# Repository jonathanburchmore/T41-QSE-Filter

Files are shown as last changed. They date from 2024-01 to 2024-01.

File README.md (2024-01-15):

# 5-Band Switching QSE Filter for T41 v11 and Older
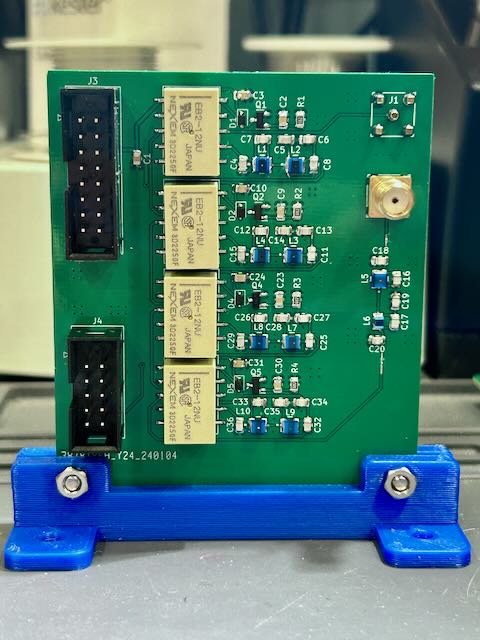
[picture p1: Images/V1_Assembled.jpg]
v1 Assembled


## Overview
This project is an automatically switched, 5-band filter board for V11 and older of the T41-EP.  Installed between the QSE and PA boards, these filters reduce harmonics that cause distortion in the PA output that cannot be removed by the output filter board.

This board is compatible with the V11 and older band switch signaling and uses a similar design to the V11 and older filter board.  The 10m filter is always active, and the 80, 40, 20 and 15 meter filters are switched in and out using relays.  With the current filter design, the 10m filter does introduce some insertion loss (see Insertion Loss below).

## Filter Characteristics
The filters used are from the ARRL Handbook, 99th edition, chapter 10.10.4 Optimized Harmonic Transmitting Filters.  They are low-pass filters (not band-pass), and are constructed using SMD components.  Most inductors are Coilcraft 1008CS series (1008 footprint), except for one Murata 0805 inductor in the 10m filter, as there was no 1008 footprint equivalent.

The following filter sweeps include the 10m filter in place so they reflect the loss characteristics described below for the lower bands.

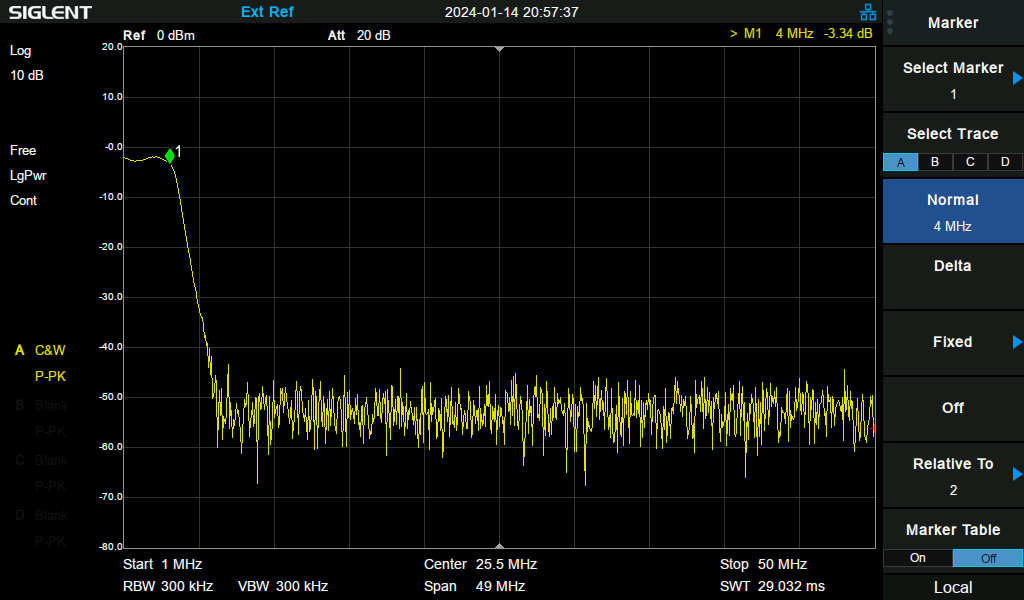
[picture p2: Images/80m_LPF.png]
80m LPF


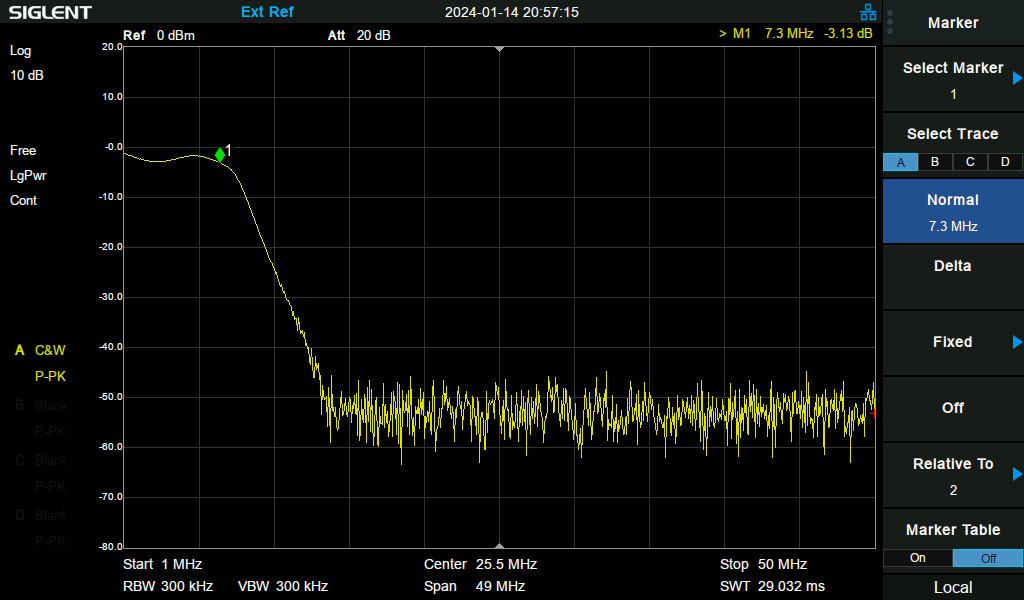
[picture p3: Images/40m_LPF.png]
40m LPF


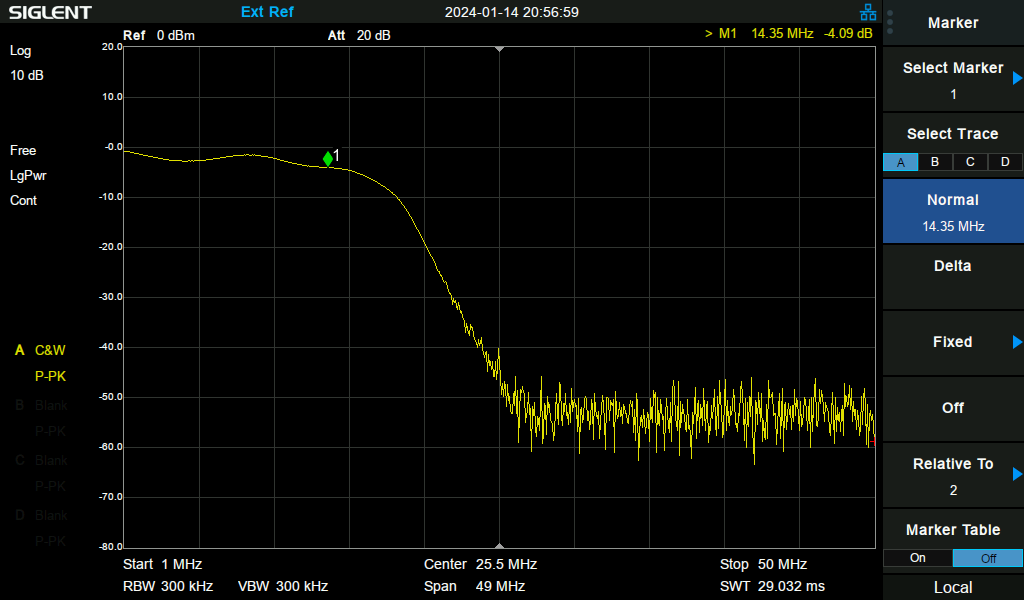
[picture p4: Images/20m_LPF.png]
20m LPF


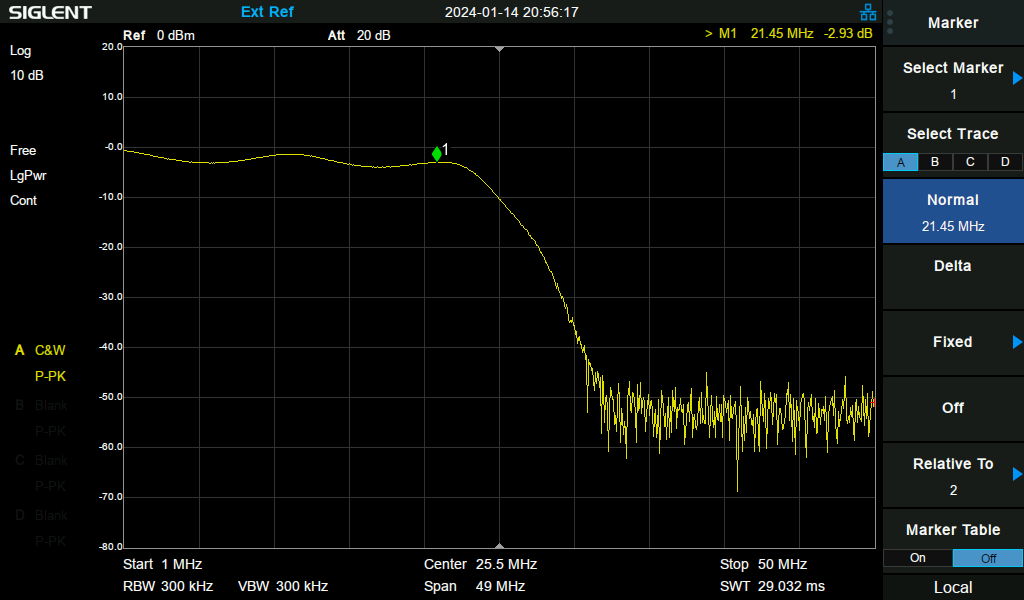
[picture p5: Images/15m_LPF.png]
15m LPF


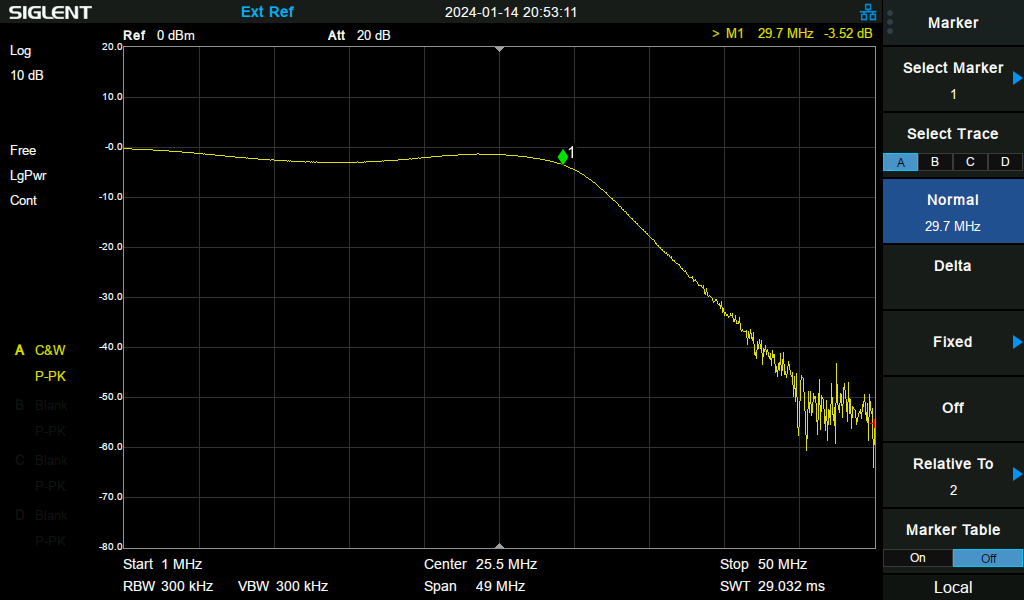
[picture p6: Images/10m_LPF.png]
10m LPF


## Insertion Loss
The PCB design is 2-layer and the RF traces are not impedance matched.  Despite this, the board itself shows negligible insertion loss and a relatively flat SWR through 35MHz.

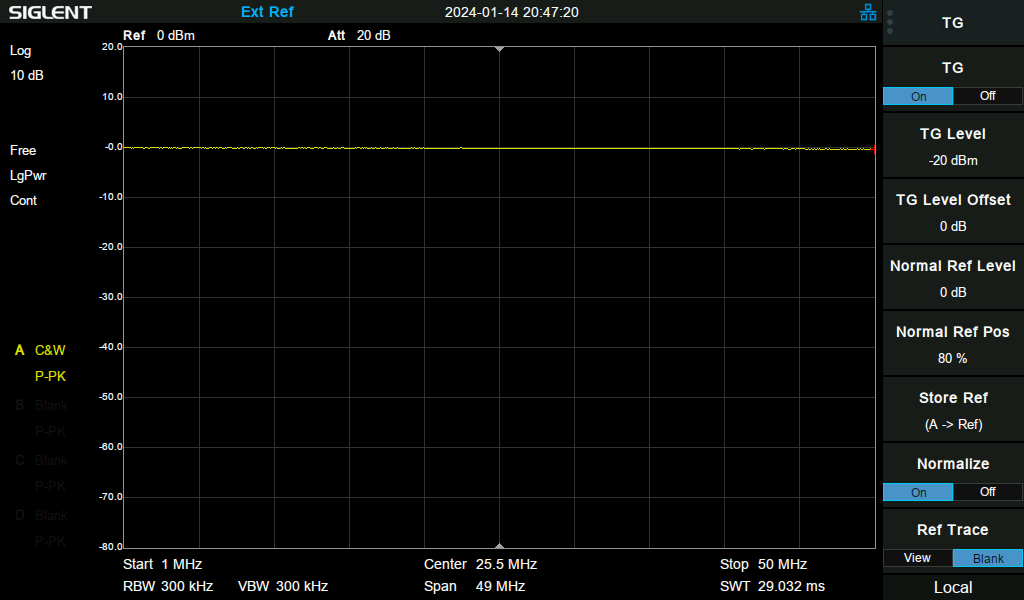
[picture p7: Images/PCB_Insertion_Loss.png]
Insertion Loss thru 50MHz


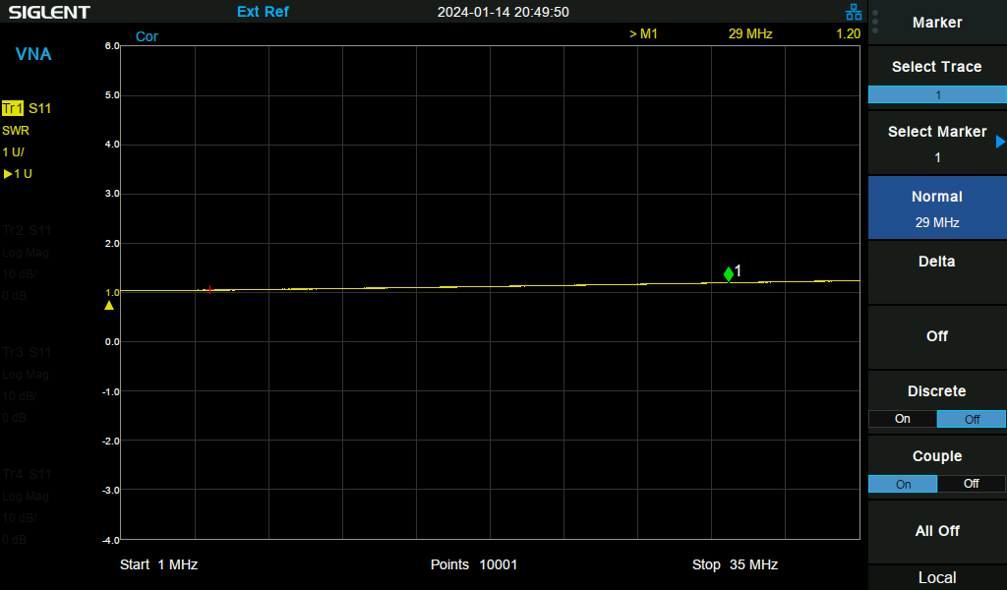
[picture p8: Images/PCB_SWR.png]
SWR through 35MHz


Nevertheless, as can be seen from the filter sweeps above, most of the filters demonstrate approximately 3db of loss.  This is largely due to the presence of the 10m filter, which, as can be seen in the sweep under Filter Characteristics, has a sizeable dip between 5-20MHz.  This characteristic is visible in simulation of the filter so is not due to the construction or part tolerances, and the impact on the other filters has been observed by bypassing the 10m filter.

In the scans below, the 20m filter is shown first with the 10m filter bypassed, and then with it present (note that the trace has a -20dBm offset):

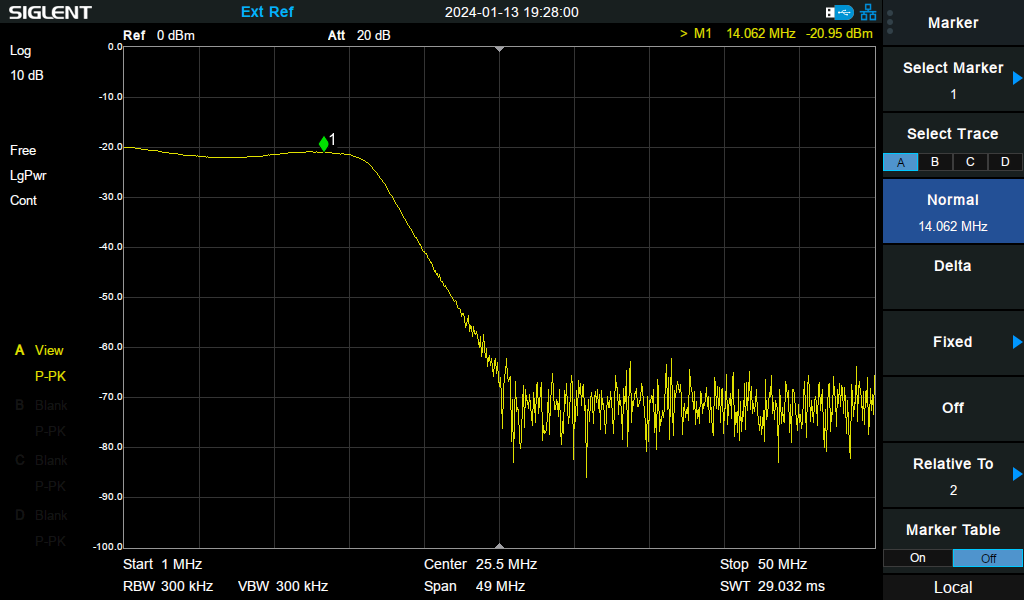
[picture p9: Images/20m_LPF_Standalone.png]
20m LPF Standalone


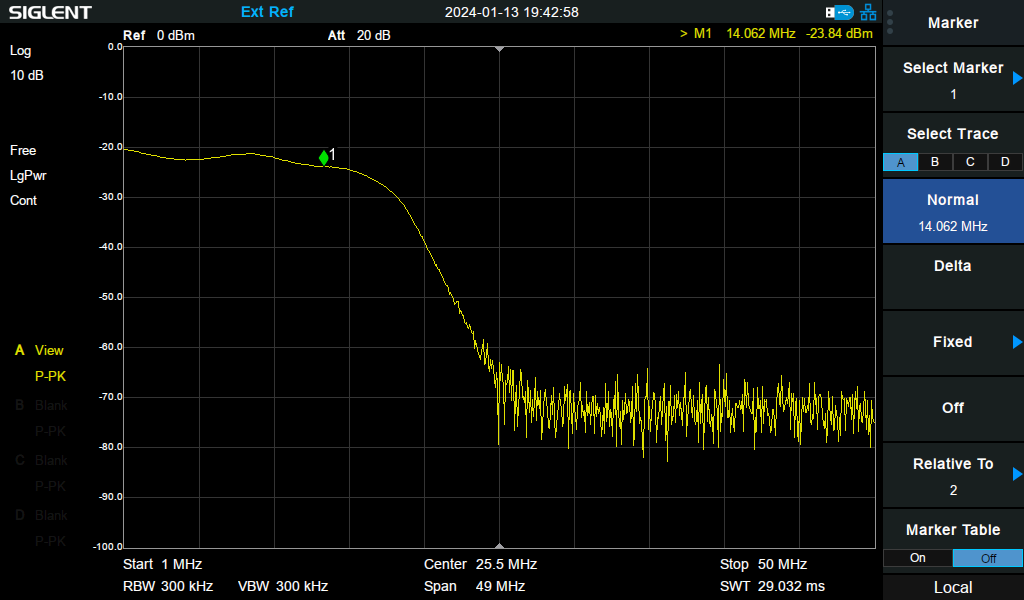
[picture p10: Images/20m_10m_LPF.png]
20m+10m LPF


This loss could perhaps be avoided through a different design to the 10m LPF, or by redesigning the board to switch the 10m LPF in only when no other band is active.  In practice, however, I have found little effect from the additional loss and it is easily compensated for through the T41's PA calibration, with no reduction in total power output.

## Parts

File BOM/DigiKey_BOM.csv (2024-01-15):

Source: | C:\Users\burch\Documents\QSE Filter\QSE Filter.kicad_sch
Date: | 1/2/24 21:57
Tool: | Eeschema 7.0.8
Generator: | C:\Program Files\KiCad\7.0\bin\scripting\plugins/bom_csv_grouped_by_value.py
Component Count: | 60
Collated Components:
Item | Qty | Reference(s) | Value | Digikey Part Number | LibPart | Footprint | Datasheet | DNP | Sim.Device | Sim.Pins
1 | 9 | C1, C2, C3, C9, C10, C23, C24, C30, C31 | 0.1uF | 1276-1003-1-ND | Device:C_Small | Capacitor_SMD:C_0805_2012Metric | ~
2 | 2 | C4, C14 | 1300pF | 490-8290-1-ND | Device:C | Capacitor_SMD:C_0805_2012Metric | ~
3 | 1 | C5 | 2400pF | 490-1629-1-ND | Device:C | Capacitor_SMD:C_0805_2012Metric | ~
4 | 1 | C6 | 1100pF | 399-14552-1-ND | Device:C | Capacitor_SMD:C_0805_2012Metric | ~
5 | 3 | C7, C18, C20 | 180pF | 399-C0805C181J5GAC7800CT-ND | Device:C | Capacitor_SMD:C_0805_2012Metric | ~
6 | 2 | C8, C19 | 390pF | 399-C0805C391J5GAC7800CT-ND | Device:C | Capacitor_SMD:C_0805_2012Metric | ~
7 | 2 | C11, C36 | 220pF | 399-C0805C221J5GAC7800CT-ND | Device:C | Capacitor_SMD:C_0805_2012Metric | ~
8 | 1 | C12 | 91pF | 311-4244-1-ND | Device:C | Capacitor_SMD:C_0805_2012Metric | ~
9 | 1 | C13 | 560pF | 311-1120-1-ND | Device:C | Capacitor_SMD:C_0805_2012Metric | ~
10 | 1 | C15 | 680pF | 311-1121-1-ND | Device:C | Capacitor_SMD:C_0805_2012Metric | ~
11 | 1 | C16 | 62pF | 311-4241-1-ND | Device:C | Capacitor_SMD:C_0805_2012Metric | ~
12 | 1 | C17 | 27pF | 311-1104-1-ND | Device:C | Capacitor_SMD:C_0805_2012Metric | ~
13 | 1 | C25 | 110pF | 399-15438-1-ND | Device:C | Capacitor_SMD:C_0805_2012Metric | ~
14 | 1 | C26 | 47pF | 399-C0805C470J5GAC7210CT-ND | Device:C | Capacitor_SMD:C_0805_2012Metric | ~
15 | 1 | C27 | 300pF | 490-12550-2-ND | Device:C | Capacitor_SMD:C_0805_2012Metric | ~
16 | 1 | C28 | 620pF | 311-4242-1-ND | Device:C | Capacitor_SMD:C_0805_2012Metric | ~
17 | 1 | C29 | 330pF | 399-C0805C331J5GAC7800CT-ND | Device:C | Capacitor_SMD:C_0805_2012Metric | ~
18 | 1 | C32 | 82pF | 311-1110-1-ND | Device:C | Capacitor_SMD:C_0805_2012Metric | ~
19 | 1 | C33 | 36pF | 311-4236-1-ND | Device:C | Capacitor_SMD:C_0805_2012Metric | ~
20 | 1 | C34 | 240pF | 311-4232-1-ND | Device:C | Capacitor_SMD:C_0805_2012Metric | ~
21 | 1 | C35 | 510pF | 311-4240-1-ND | Device:C | Capacitor_SMD:C_0805_2012Metric | ~
22 | 4 | D1, D2, D4, D5 | 1N4148WS | 1N4148WSF-7DICT-ND | Diode:1N4148WS | Diode_SMD:D_SOD-323 | https://www.vishay.com/docs/85751/1n4148ws.pdf |  | D | 1=K 2=A
23 | 1 | J1 | RF In | 2057-RF2-04A-T-00-50-G-ND | Connector:Conn_Coaxial | Connector_Coaxial:SMA_Amphenol_132134_Vertical | ~
24 | 1 | J2 | RF Out | 2057-RF2-04A-T-00-50-G-ND | Connector:Conn_Coaxial | Connector_Coaxial:SMA_Amphenol_132134_Vertical | ~
25 | 1 | J3 | Power | 1175-1611-ND | Connector_Generic:Conn_02x08_Odd_Even | Connector_IDC:IDC-Header_2x08_P2.54mm_Vertical | ~
26 | 1 | J4 | Control In | 3020-10-0100-00 | Connector_Generic:Conn_02x05_Odd_Even | Connector_IDC:IDC-Header_2x05_P2.54mm_Vertical | ~
27 | 1 | L1 | 1.5uH | 2457-1008CS-152XJRC-ND | Device:L | IND_1008CS_COC:IND_1008CS_COC | ~
28 | 1 | L2 | 1.3uH | 2457-1008CS-132XJRC-ND | Device:L | IND_1008CS_COC:IND_1008CS_COC | ~
29 | 1 | L3 | 620nH | 2457-1008CS-621XJRC-ND | Device:L | IND_1008CS_COC:IND_1008CS_COC | ~
30 | 1 | L4 | 750nH | 2457-1008CS-751XJRC-ND | Device:L | IND_1008CS_COC:IND_1008CS_COC | ~
31 | 1 | L5 | 180nH | 2457-1008CS-181XJRC-ND | Device:L | IND_1008CS_COC:IND_1008CS_COC | ~
31 | 1 | L6 | 200nH | 490-16070-1-ND | Device:L | IND_1008CS_COC:IND_1008CS_COC | ~
32 | 1 | L7 | 330nH | 2457-1008CS-331XJRC-ND | Device:L | IND_1008CS_COC:IND_1008CS_COC | ~
33 | 1 | L8 | 390nF | 2457-1008CS-391XJRC-ND | Device:L | IND_1008CS_COC:IND_1008CS_COC | ~
34 | 1 | L9 | 220nH | 2457-1008CS-221XJRC-ND | Device:L | IND_1008CS_COC:IND_1008CS_COC | ~
34 | 1 | L10 | 270nH | 2457-1008CS-271XJRC-ND | Device:L | IND_1008CS_COC:IND_1008CS_COC | ~
35 | 4 | Q1, Q2, Q4, Q5 | 2N7002 | 1727-4789-1-ND | Transistor_FET:2N7002 | Package_TO_SOT_SMD:SOT-23 | https://www.onsemi.com/pub/Collateral/NDS7002A-D.PDF
36 | 4 | U1, U2, U4, U5 | EB2-12NU | EB2-12NU-ND | Kemet EB2-12NU-L:EB2-12NU | Kemet_EB2:EB2-12NU_KEM | EB2-12NU
37 | 4 | R1,R2,R3,R4 | 6.8K | RMCF0805JT6K80CT-ND

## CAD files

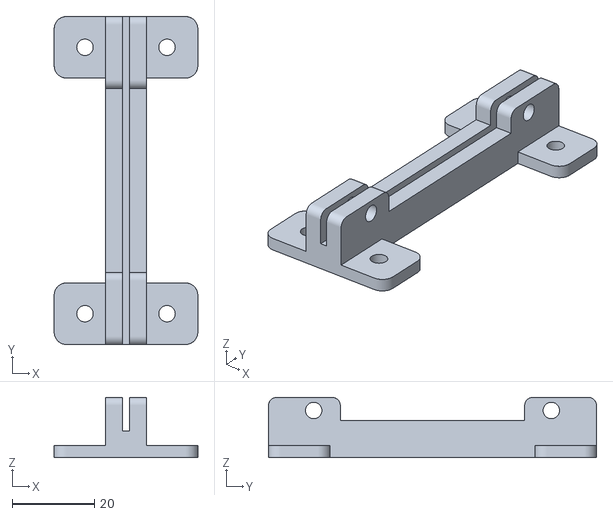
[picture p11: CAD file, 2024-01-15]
STL/Mounting_Bracket.stl
35.0 x 79.9 x 14.7

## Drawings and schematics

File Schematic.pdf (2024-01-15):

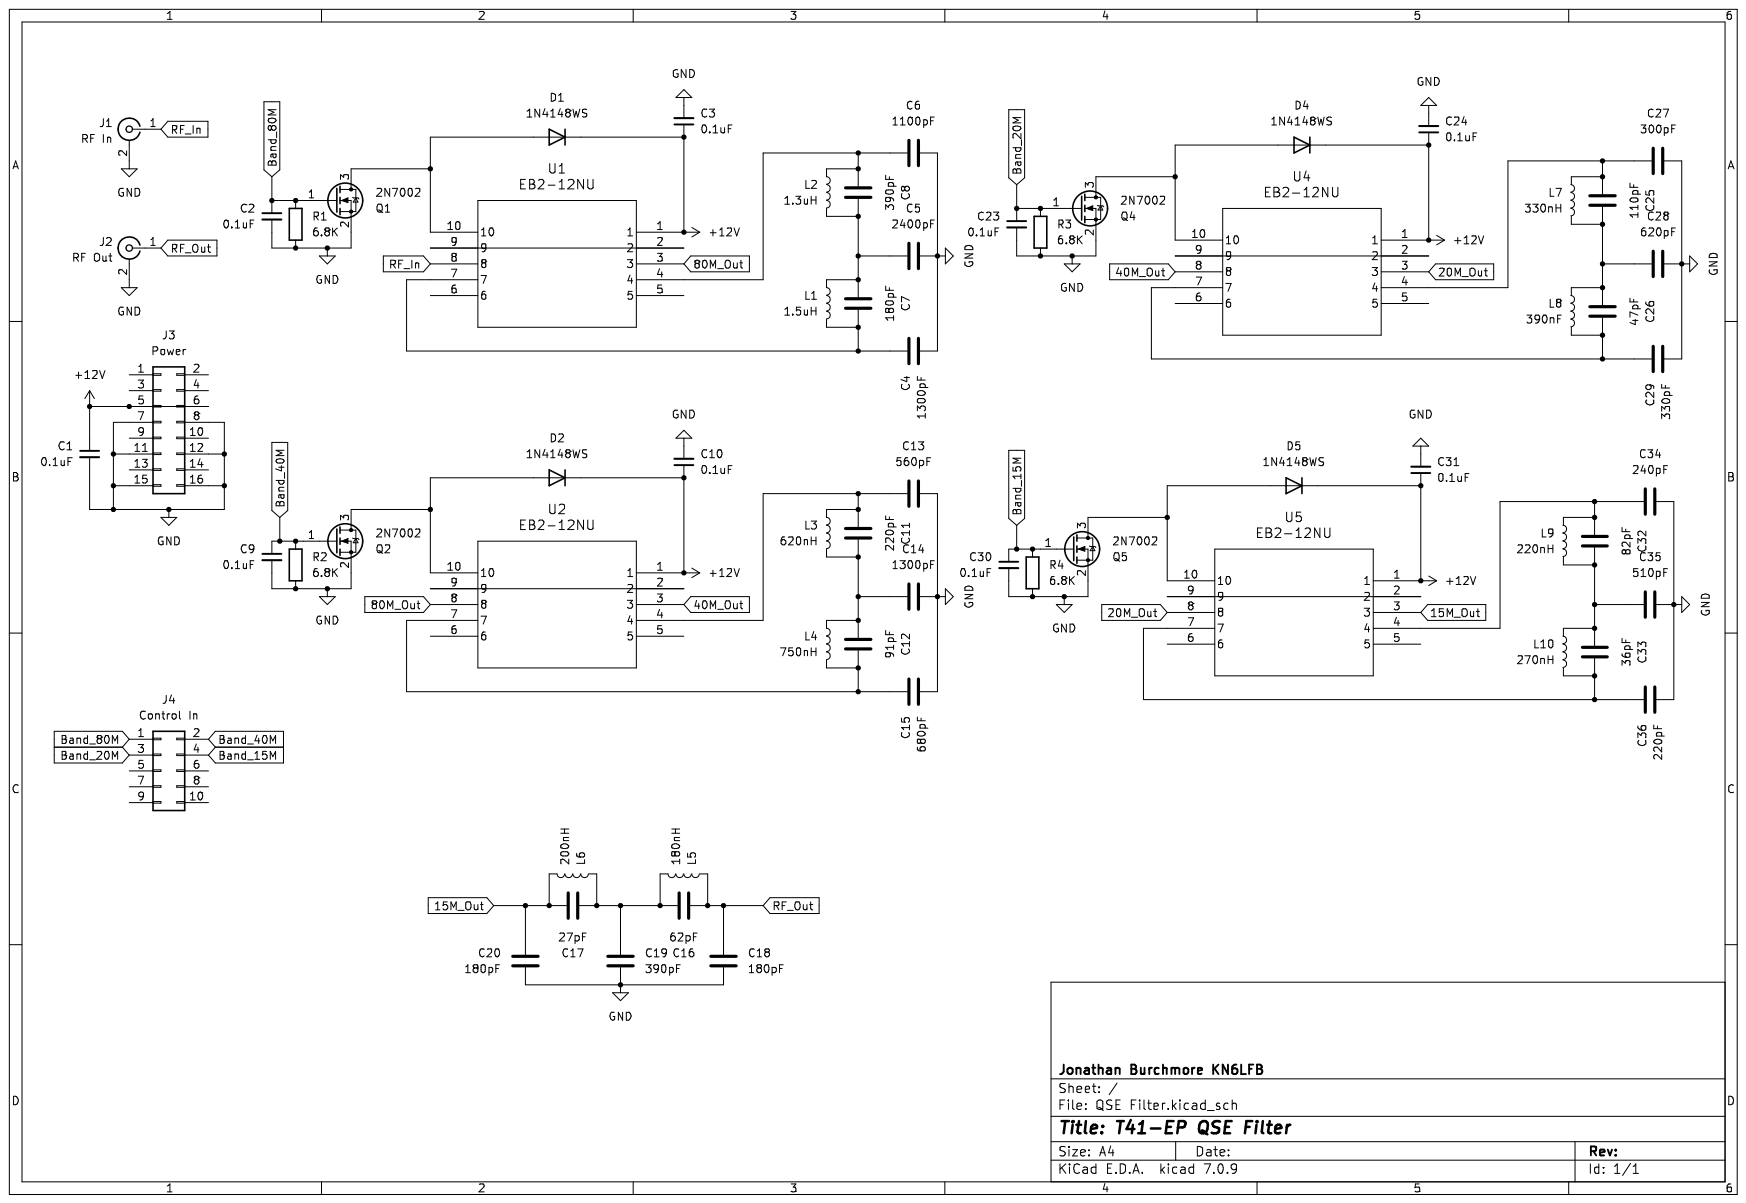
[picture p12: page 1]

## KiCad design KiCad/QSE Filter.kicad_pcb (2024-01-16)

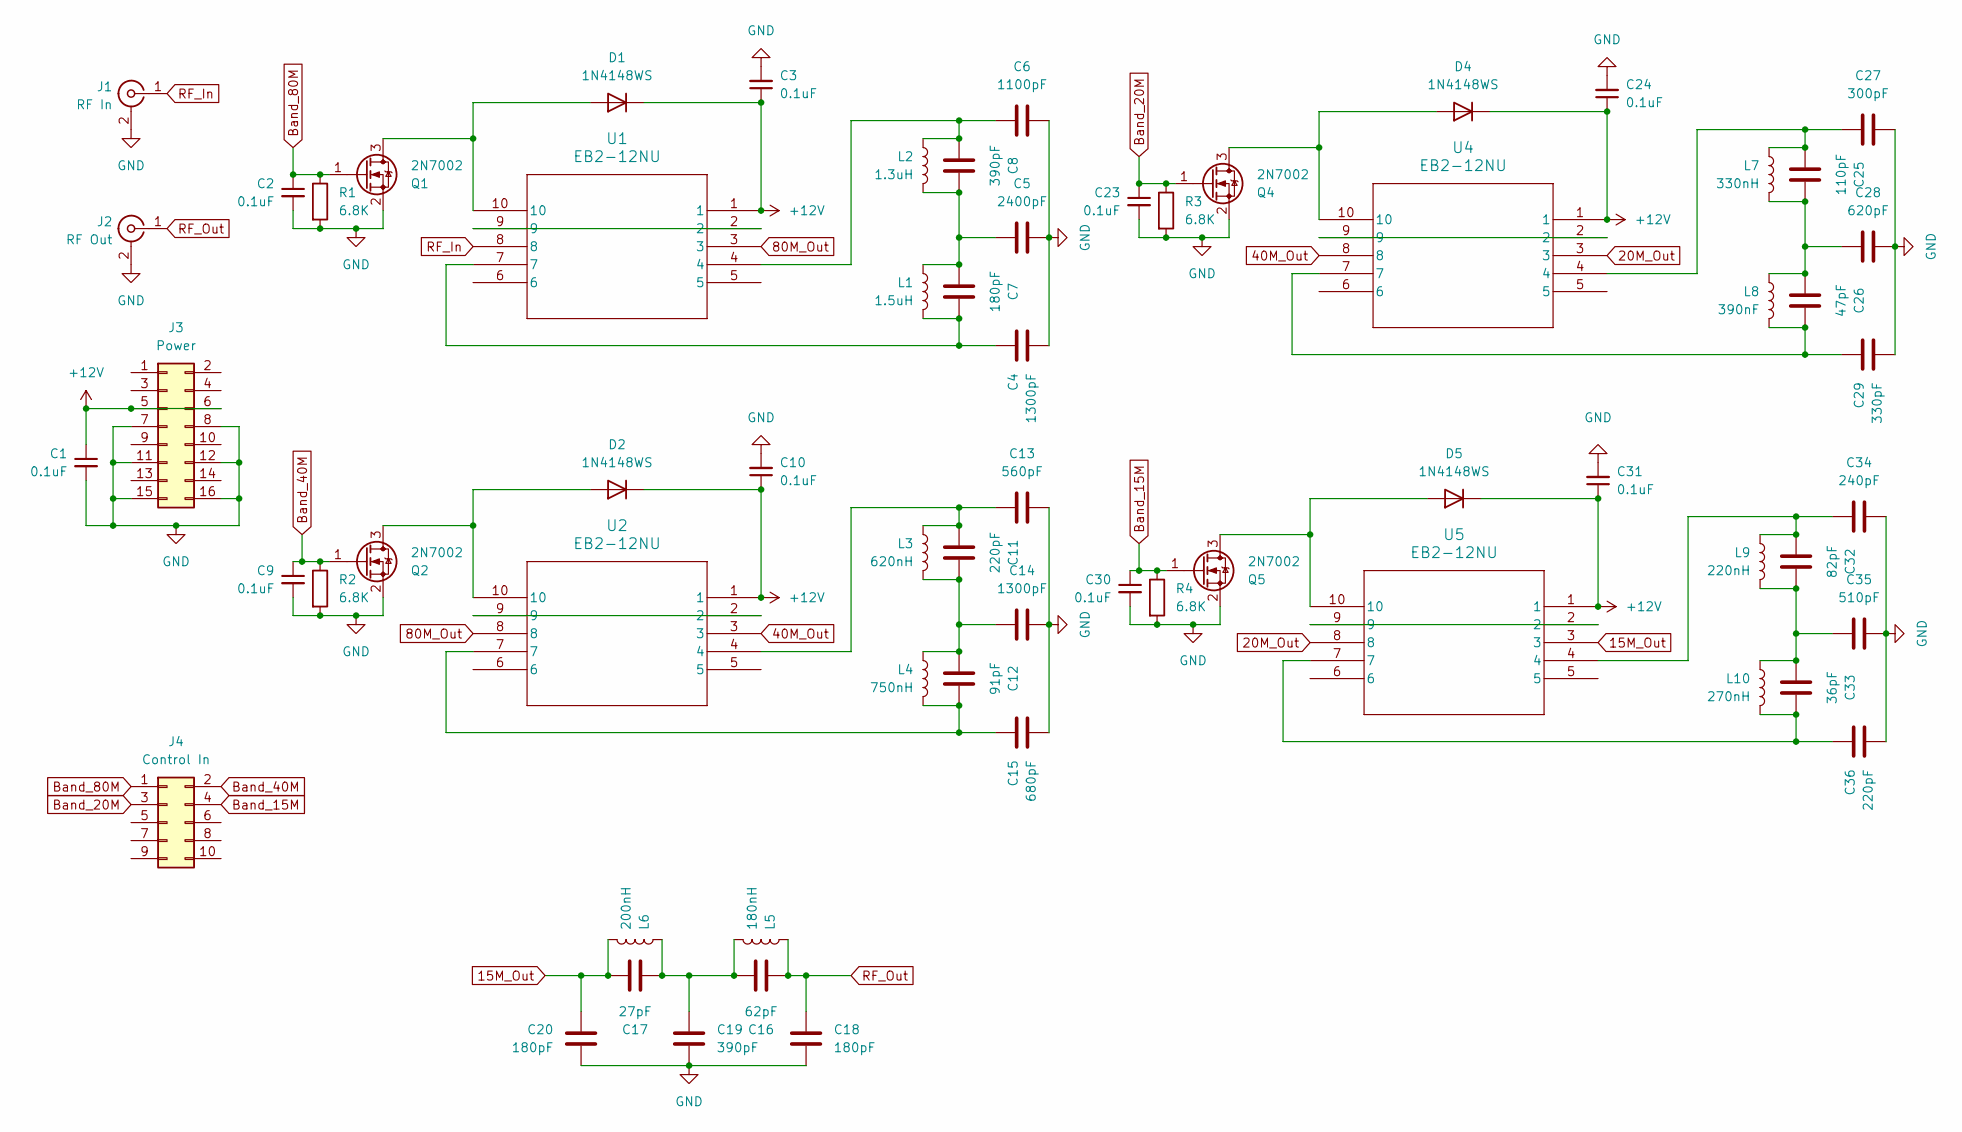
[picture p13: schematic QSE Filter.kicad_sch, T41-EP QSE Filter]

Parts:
C1, C2, C3, C9, C10, C23, C24, C30, C31: 0.1uF; C_0805_2012Metric
C4, C14: 1300pF; C_0805_2012Metric
C5: 2400pF; C_0805_2012Metric
C6: 1100pF; C_0805_2012Metric
C7, C18, C20: 180pF; C_0805_2012Metric
C8, C19: 390pF; C_0805_2012Metric
C11, C36: 220pF; C_0805_2012Metric
C12: 91pF; C_0805_2012Metric
C13: 560pF; C_0805_2012Metric
C15: 680pF; C_0805_2012Metric
C16: 62pF; C_0805_2012Metric
C17: 27pF; C_0805_2012Metric
C25: 110pF; C_0805_2012Metric
C26: 47pF; C_0805_2012Metric
C27: 300pF; C_0805_2012Metric
C28: 620pF; C_0805_2012Metric
C29: 330pF; C_0805_2012Metric
C32: 82pF; C_0805_2012Metric
C33: 36pF; C_0805_2012Metric
C34: 240pF; C_0805_2012Metric
C35: 510pF; C_0805_2012Metric
D1, D2, D4, D5: 1N4148WS; D_SOD-323
J1: RF In; CONN_RF2-04A-T-00-50-G_ADM
J2: RF Out; CONN_RF2-04A-T-00-50-G_ADM
J3: Power; IDC-Header_2x08_P2.54mm_Vertical
J4: Control In; IDC-Header_2x05_P2.54mm_Vertical
L1: 1.5uH; IND_1008CS_COC
L2: 1.3uH; IND_1008CS_COC
L3: 620nH; IND_1008CS_COC
L4: 750nH; IND_1008CS_COC
L5: 180nH; IND_1008CS_COC
L6: 200nH; INDC2015X152N
L7: 330nH; IND_1008CS_COC
L8: 390nF; IND_1008CS_COC
L9: 220nH; IND_1008CS_COC
L10: 270nH; IND_1008CS_COC
Q1, Q2, Q4, Q5: 2N7002; SOT-23
R1, R2, R3, R4: 6.8K; R_0805_2012Metric
U1, U2, U4, U5: EB2-12NU; EB2-12NU_KEM

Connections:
15M_Out: C17.1, C20.1, L6.1, U5.3
20M_Out: U4.3, U5.8
40M_Out: U2.3, U4.8
80M_Out: U1.3, U2.8
+12V: C1.1, C3.1, C10.1, C24.1, C31.1, D1.1 (K), D2.1 (K), D4.1 (K), D5.1 (K), J3.5, J3.6, U1.1, U2.1, U4.1, U5.1
Band_15M: C30.1, J4.4, Q5.1 (G), R4.1
Band_20M: C23.1, J4.3, Q4.1 (G), R3.1
Band_40M: C9.1, J4.2, Q2.1 (G), R2.1
Band_80M: C2.1, J4.1, Q1.1 (G), R1.1
GND: C1.2, C2.2, C3.2, C4.2, C5.2, C6.2, C9.2, C10.2, C13.2, C14.2, C15.2, C18.2, C19.2, C20.2, C23.2, C24.2, C27.2, C28.2, C29.2, C30.2, C31.2, C34.2, C35.2, C36.2, J1.2 (Ext), J1.3 (Ext), J1.4 (Ext), J1.5 (Ext), J2.2 (Ext), J2.3 (Ext), J2.4 (Ext), J2.5 (Ext), J3.7, J3.8, J3.11, J3.12, J3.15, J3.16, Q1.2 (S), Q2.2 (S), Q4.2 (S), Q5.2 (S), R1.2, R2.2, R3.2, R4.2
unnamed: C4.1, C7.1, L1.1, U1.7
unnamed: C5.1, C7.2, C8.1, L1.2, L2.1
unnamed: C6.1, C8.2, L2.2, U1.4
unnamed: C11.1, C12.2, C14.1, L3.1, L4.2
unnamed: C11.2, C13.1, L3.2, U2.4
unnamed: C12.1, C15.1, L4.1, U2.7
unnamed: C16.1, C17.2, C19.1, L5.1, L6.2
unnamed: C25.1, C26.2, C28.1, L7.1, L8.2
unnamed: C25.2, C27.1, L7.2, U4.4
unnamed: C26.1, C29.1, L8.1, U4.7
unnamed: C32.1, C33.2, C35.1, L9.1, L10.2
unnamed: C32.2, C34.1, L9.2, U5.4
unnamed: C33.1, C36.1, L10.1, U5.7
unnamed: D1.2 (A), Q1.3 (D), U1.10
unnamed: D2.2 (A), Q2.3 (D), U2.10
unnamed: D4.2 (A), Q4.3 (D), U4.10
unnamed: D5.2 (A), Q5.3 (D), U5.10
unnamed: U1.2, U1.9
unnamed: U2.2, U2.9
unnamed: U4.2, U4.9
unnamed: U5.2, U5.9
RF_In: J1.1 (In), U1.8
RF_Out: C16.2, C18.1, J2.1 (In), L5.2

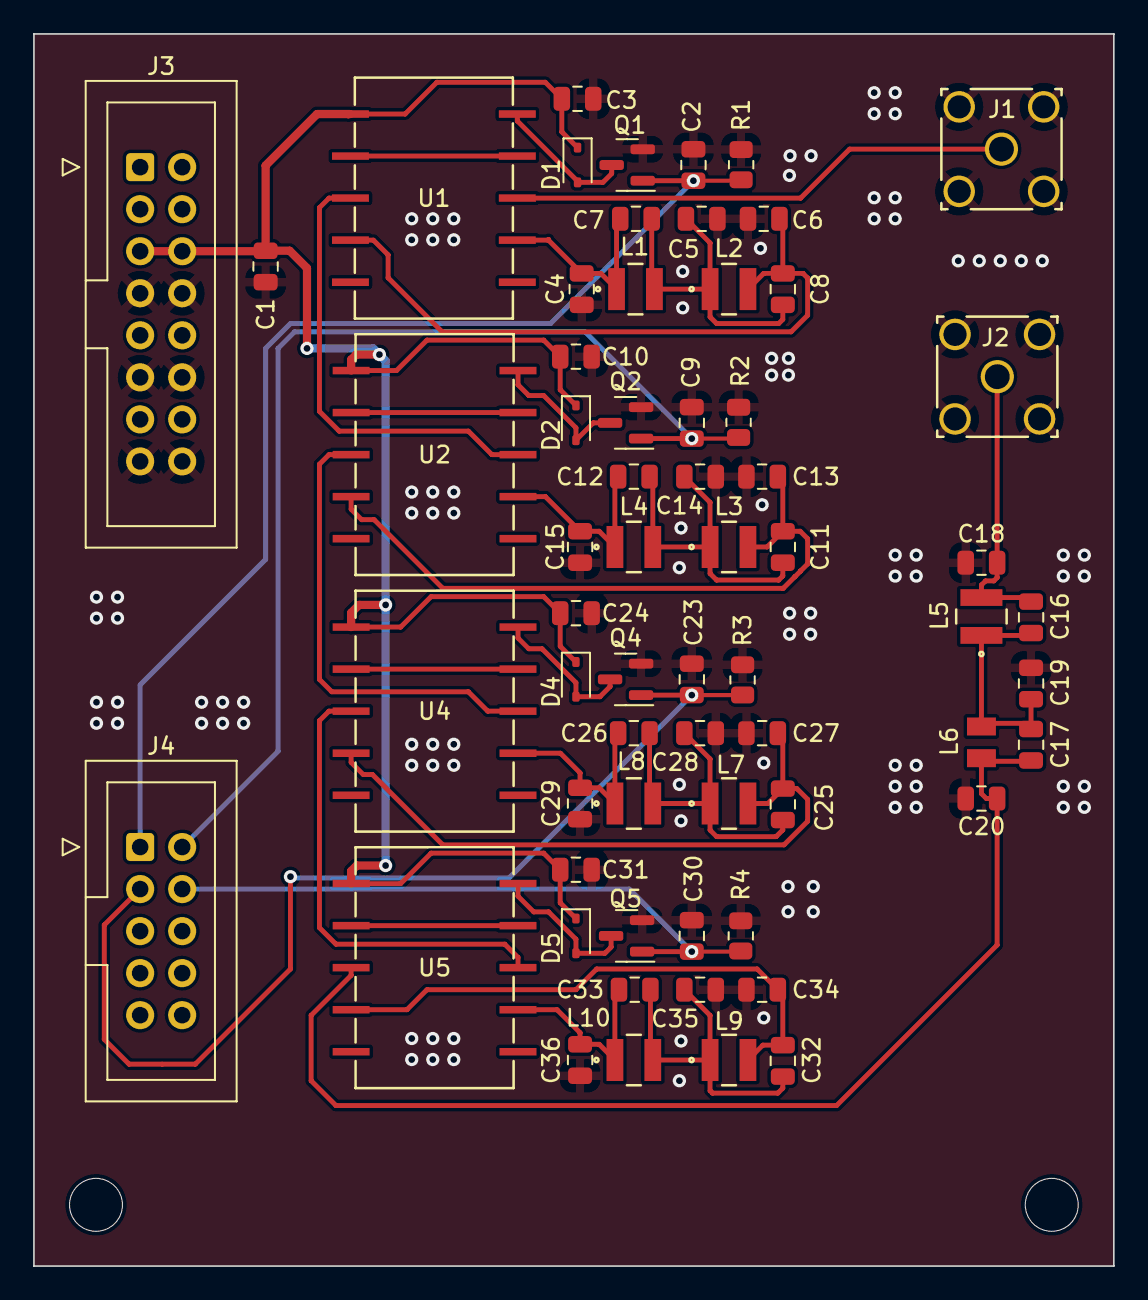
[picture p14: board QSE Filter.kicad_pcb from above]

Board: 2 copper layers, 65.2 x 74.5 mm, 64 parts (0 on the bottom side), 33 nets.

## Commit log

2024-01-15 Initial commit. V1 Gerbers, V2 KiCad, updated/corrected DigiKey BOM.
    [DigiKey_BOM.csv, Mounting_Bracket.stl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]
2024-01-15 Current schematic
2024-01-15 Photo of assembled v1 board
2024-01-15 20m insertion loss sweeps
2024-01-16 Eliminate acute angles/acid traps in various traces Move C1 slightly
    [QSE Filter.kicad_pcb]
2024-01-16 Move C1 silkscreen
    [QSE Filter.kicad_pcb]
2024-01-16 Created project symbol and footprint libraries
    [QSE Filter.kicad_pcb, QSE Filter.kicad_sch]
2024-01-16 Corrected RF connector symbol so KiCad will stop disconnecting pins 3, 4, 5, by creating a stack of invisible pins Updated all footprints and symbols to pull from the QSE Filter library
    [QSE Filter.kicad_pcb, QSE Filter.kicad_sch]
